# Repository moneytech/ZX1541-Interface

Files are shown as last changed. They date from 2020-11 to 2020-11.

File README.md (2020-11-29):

# ZX1541-Interface
An interface for the Sinclair ZX-81, with which you can use Commodore VC-1541 floppy drives.

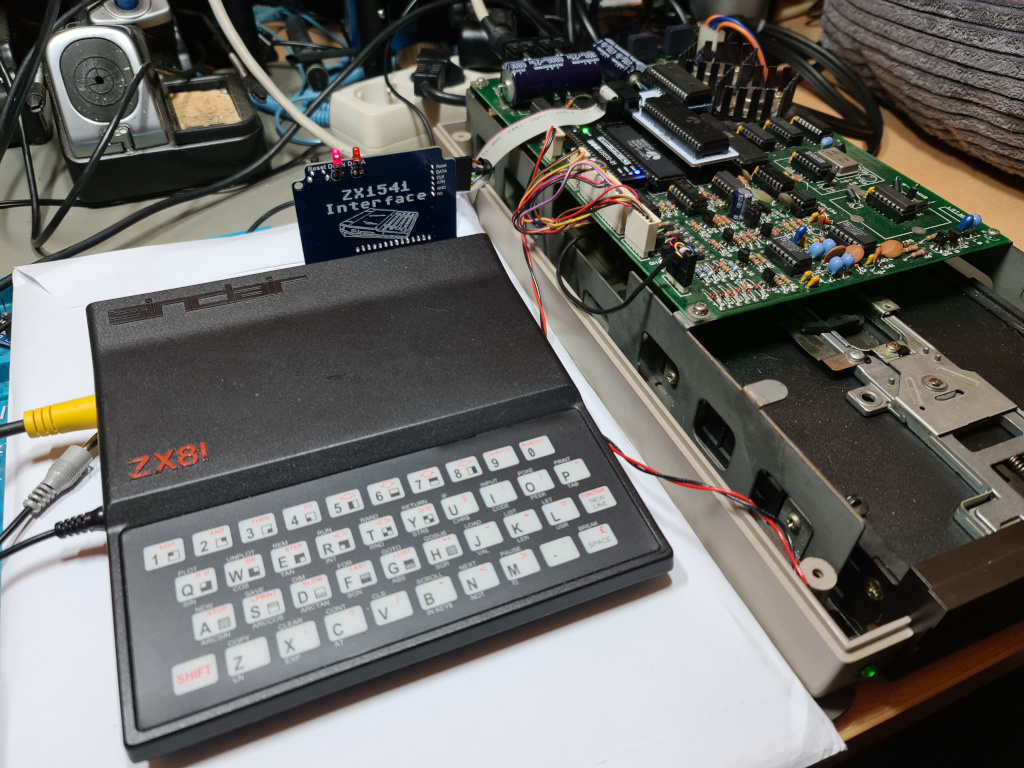
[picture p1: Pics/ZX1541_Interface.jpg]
Image of 1541 ZXInterface


Inspired by this post (https://forum.tlienhard.com/phpBB3/viewtopic.php?f=2&t=3218), I rebuilt the interface. 

The idea originally came from Luis C. Grosso
and was developed in 2004 for the model CZ1500 (a relabelled Timex Sinclair 1500)).

In 2006 Jarek Adamski took up the subject and made some modifications for use with a Sinclair ZX-81.

For this purpose, there is also a website with further information at http://8bit.yarek.pl/interface/zx81.zx1541/index-de.html.

Unfortunately most of the downloads are no longer available there. Whatever files I could find on the internet, I uploaded into this repository. 

I then created a new schematic using the information available there. Additionally some modifications from the above mentioned thread were included.

The board is designed to fit into an old case of the original Sinclair 16kb RAM expansion.

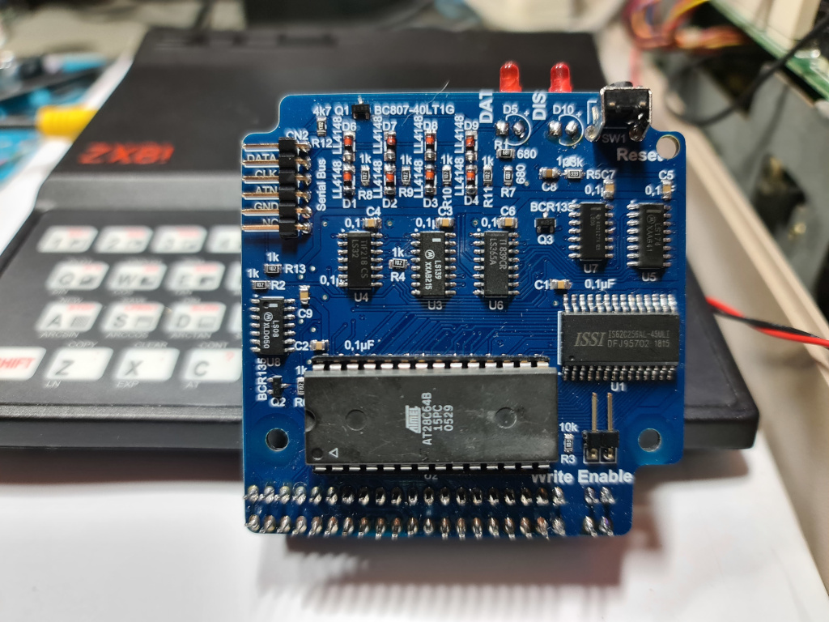
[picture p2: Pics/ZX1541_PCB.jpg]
Image of 1541 ZXInterface PCB


For the interface to work, a memory expansion is required. Without it there is not enough memory available for the extension to work. The best way to do this is to upgrade the ZX-81 internally.

The interface is equipped with an EEPROM, which contains the firmware. This can be called with the following command:

    RAND USR 8192

In firmware version 1.3 the start screen looks like this:

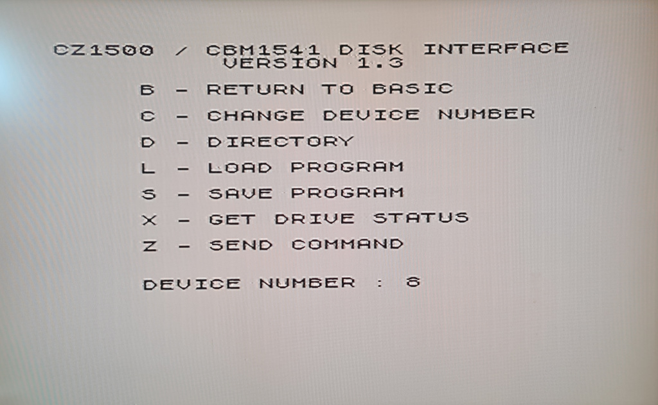
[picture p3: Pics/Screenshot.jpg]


## Parts List ##

Here is the list of all required parts

|Designator|Item|Type|
|---|----|----|
|U1|IS62C256AL-45ULI|SO28|
|U2|AT28C64B-15PC|DIP28|
|U3|74LS139|SO16|
|U4|74LS32|SO14|
|U5|74LS174|SO16|
|U6|74LS365|SO16|
|U7|74LS06|SO14|
|U8|74LS08|SO14|
|Q1|BC807-40|SOT23|
|Q2-3|BCR135|SOT23|
|D1-4, 6-9|LL4148|miniMELF|
|D5|LED red 3mm|THT|
|D10|LED green, 3mm|THT|
|R1,7|680R|0805|
|R2,4,6,8-11,13|1K|0805|
|R3|10K|0805|
|R5|33K|0805|
|R12|4K7|0805|
|C1-7,9|100nF|0805|
|C8|1µF|0805|
|CN2|Pin Header, RM2.54mm, 6pos, right angle|THT|
|JP1|Pin Header, RM2.54, 2pos.|THT|
|SW1|Push button, 6x6mm, right angle|THT|
|For U2|IC Socket 28pos.|DIL28|

Unless otherwise stated:
resistors tolerance 5% or better
Capacitors: X5R or better, 16V or higher

In addition, an approx. 60cm long, 6-core cable, a 6-pin DIN socket in "horseshoe shape" and a 6-pin female connector strip for the connection cable to the floppy is required.

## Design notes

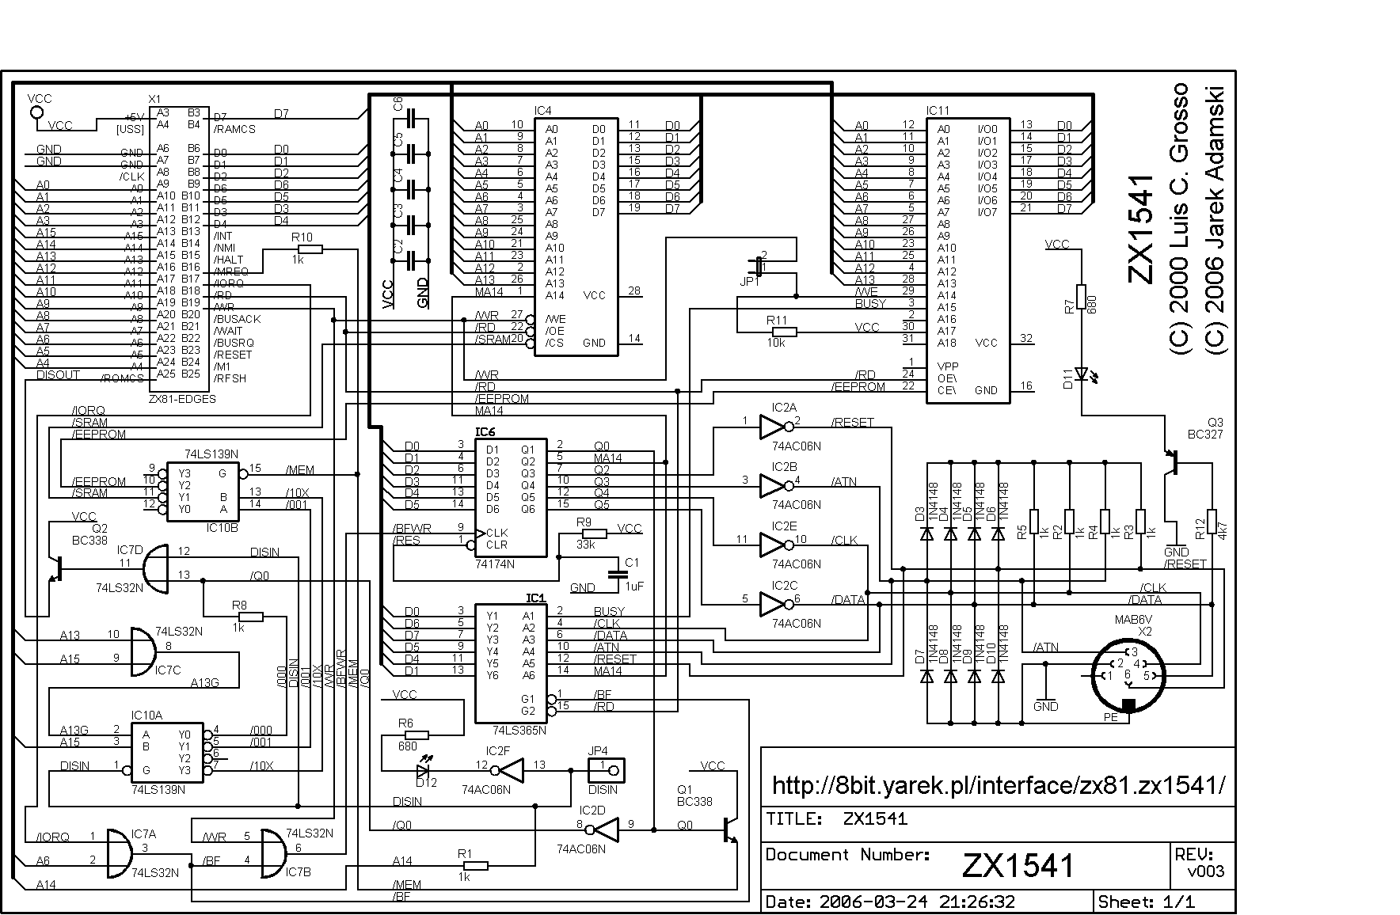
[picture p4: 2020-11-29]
files_found_on_the_internet/Schematics/zx1541v003.png

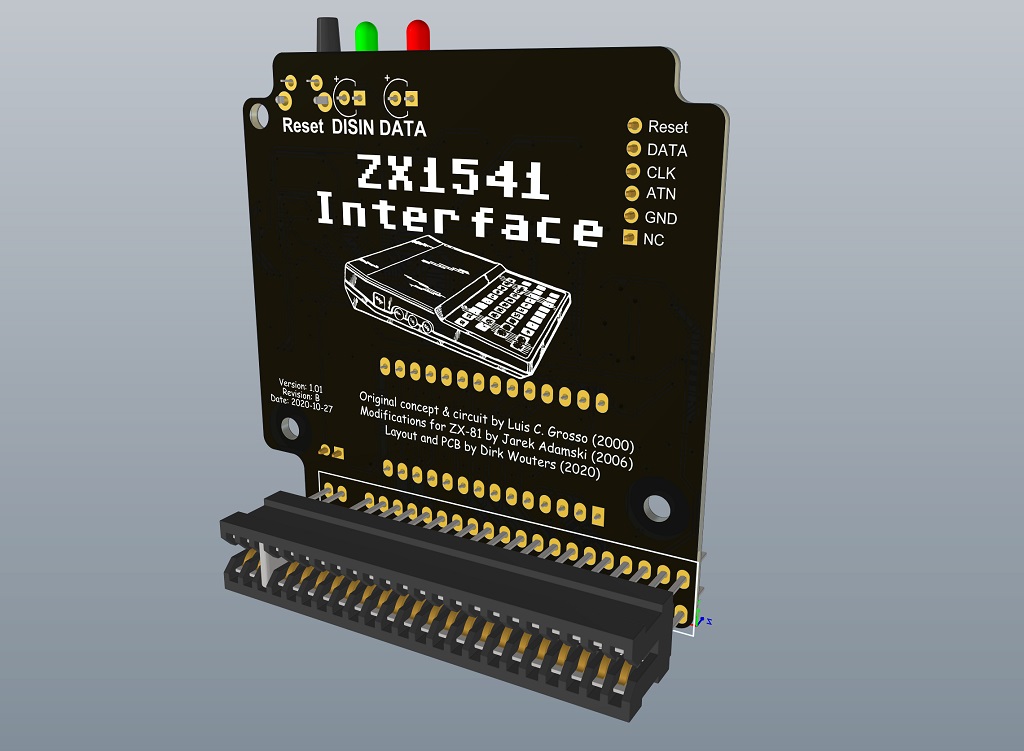
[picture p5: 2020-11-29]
Pics/PCB_back.jpg

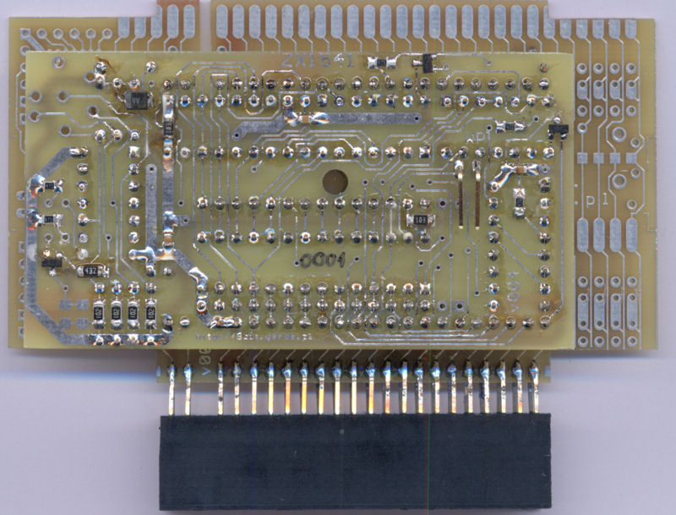
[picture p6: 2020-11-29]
files_found_on_the_internet/Pictures/0001c.jpg

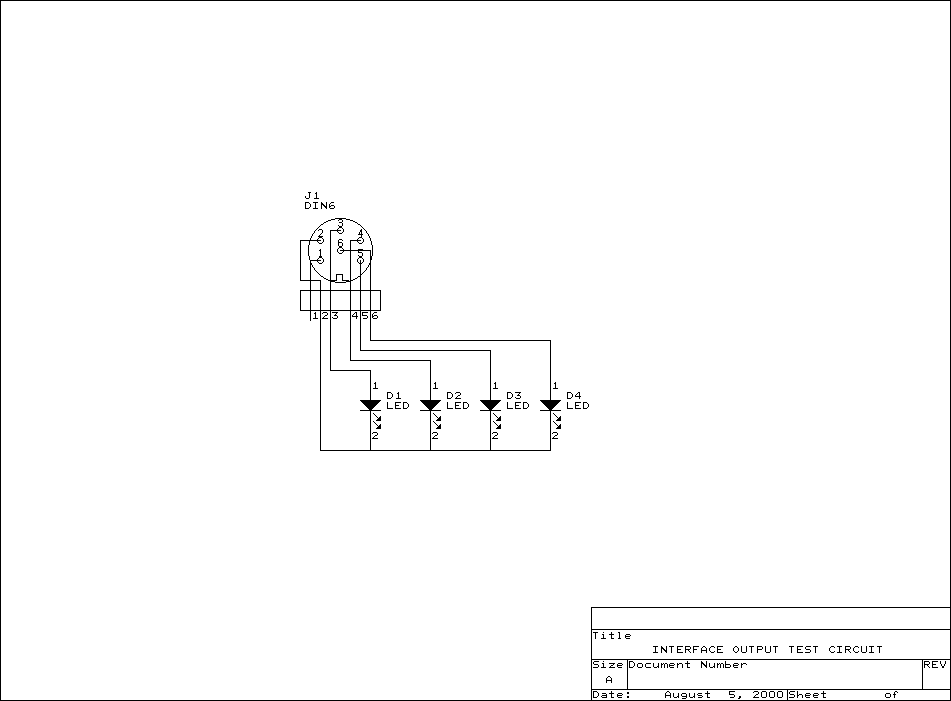
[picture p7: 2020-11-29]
files_found_on_the_internet/Pictures/LEDS.GIF

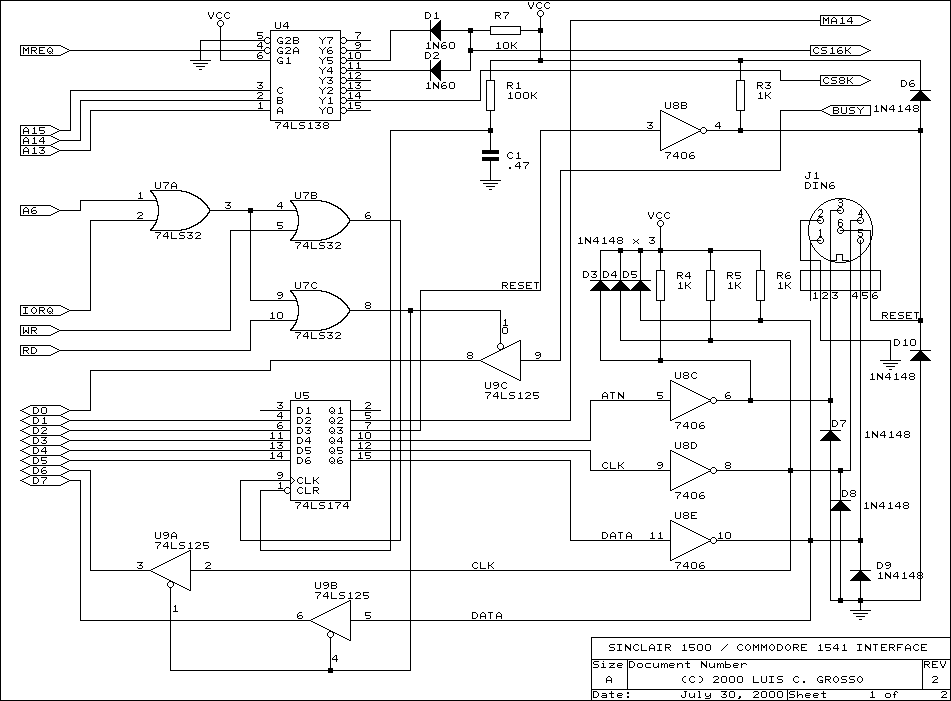
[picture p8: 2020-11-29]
files_found_on_the_internet/Pictures/1500DSK1.GIF

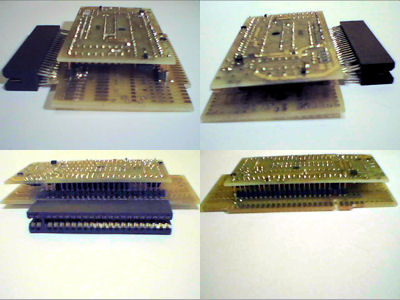
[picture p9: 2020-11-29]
files_found_on_the_internet/Pictures/0001b.jpg

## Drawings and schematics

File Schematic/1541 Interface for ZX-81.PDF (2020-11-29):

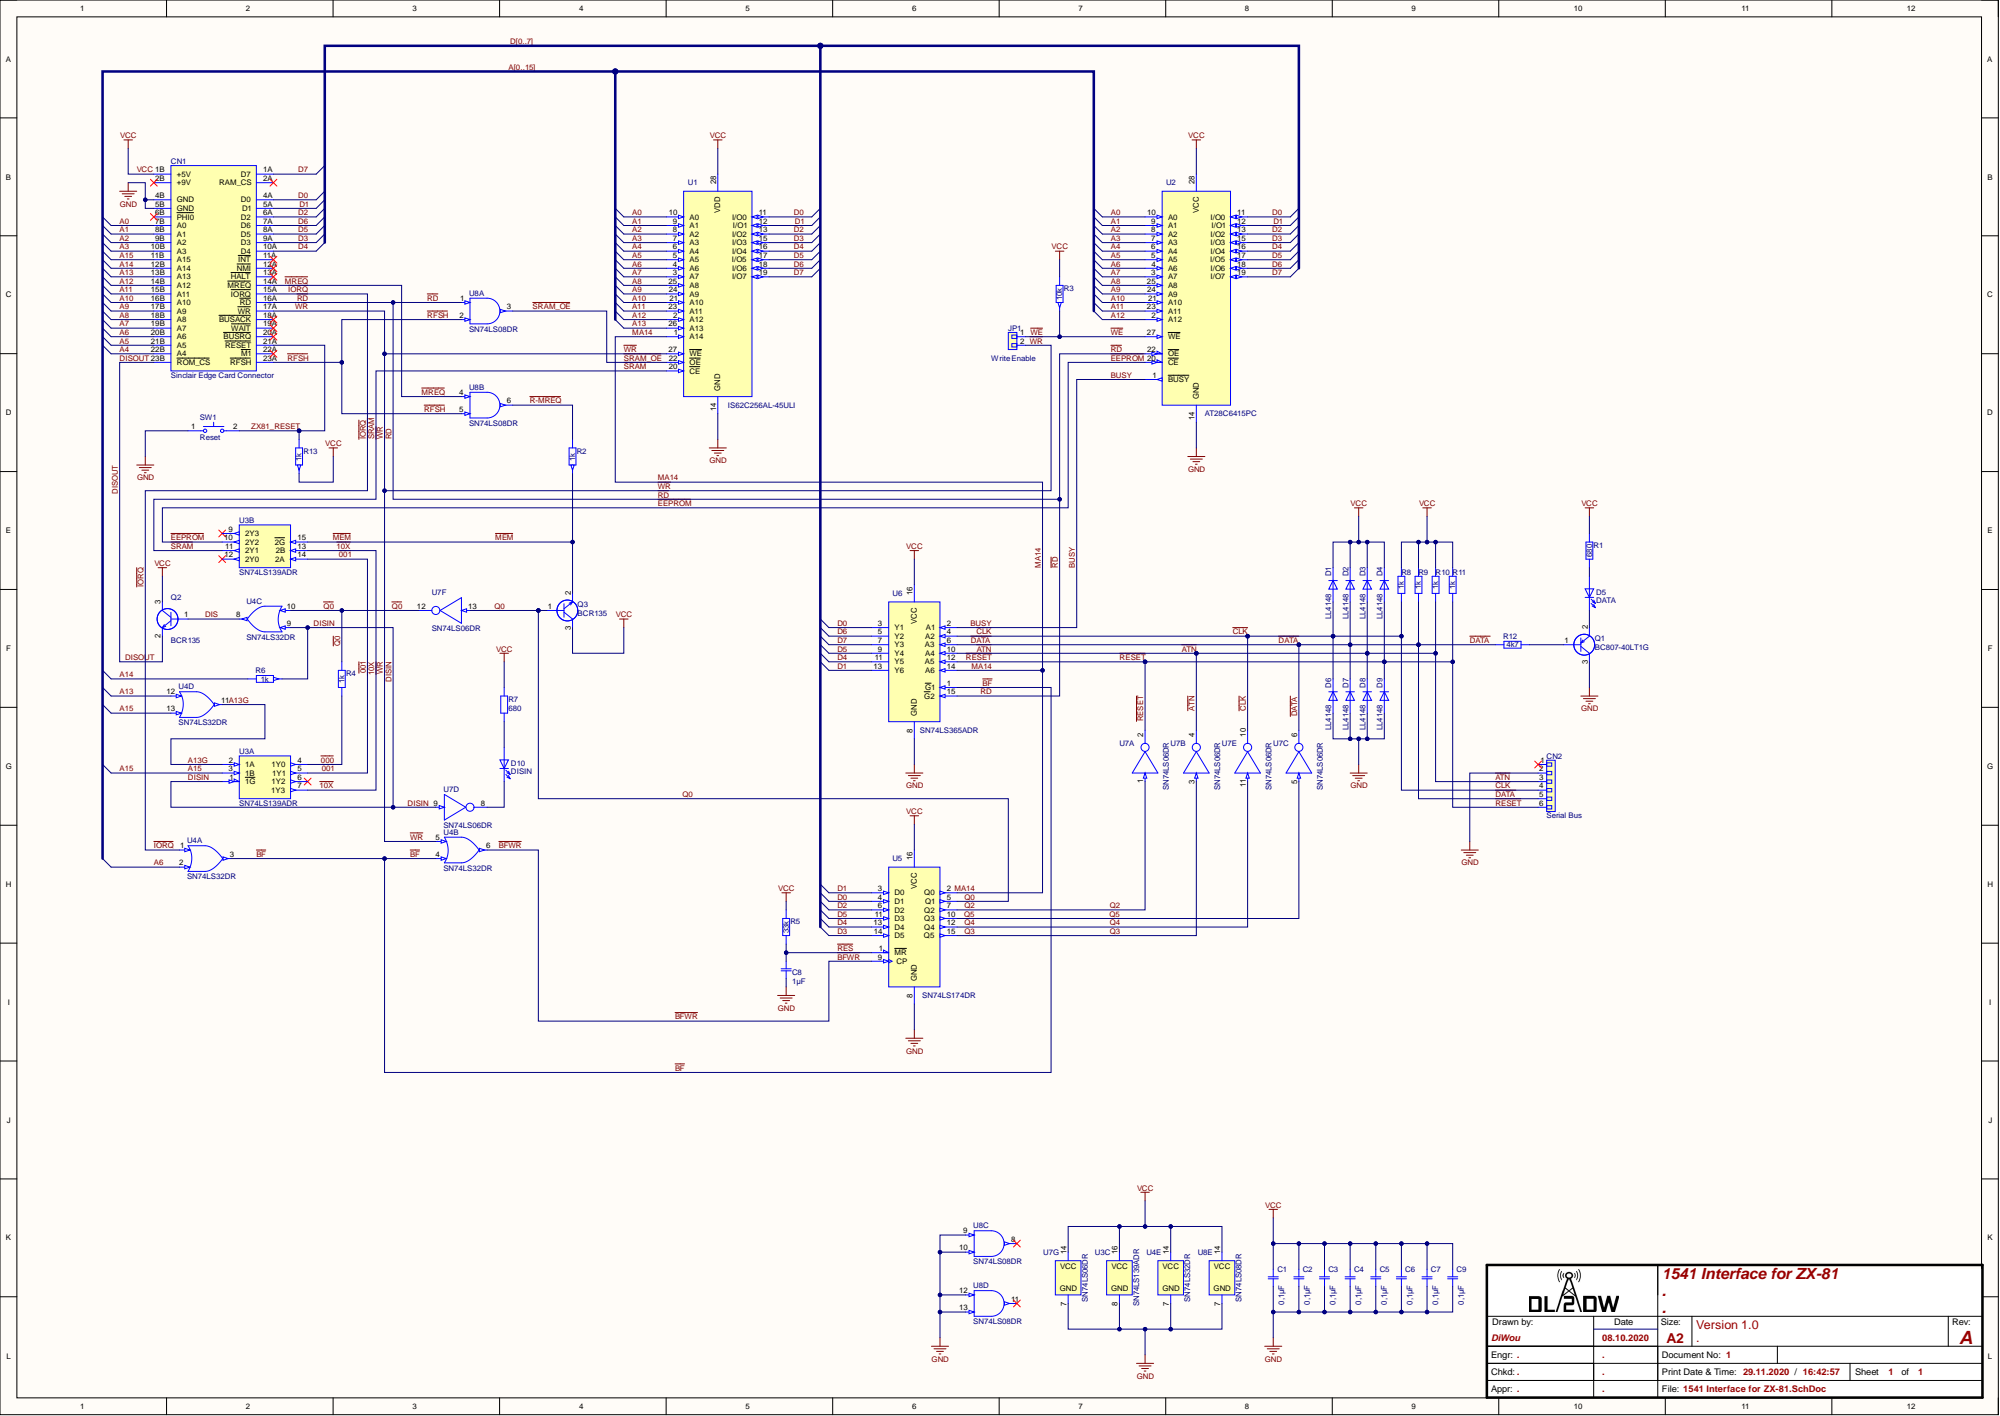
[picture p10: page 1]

VCC | VCC | VCC

Sinclair Edge Card Connector

RD
EEPROM

U3B | | MEM | | VCC

DISIN | U4B BFWR | Q0 | | RD

1541 Interface for ZX-81 . .

Engr: . | . | Document No: 1

Chkd: . | . | Print Date & Time: 29.11.2020 / 16:42:57 | Sheet 1 of 1

Appr: . | . | File: 1541 Interface for ZX-81.SchDoc

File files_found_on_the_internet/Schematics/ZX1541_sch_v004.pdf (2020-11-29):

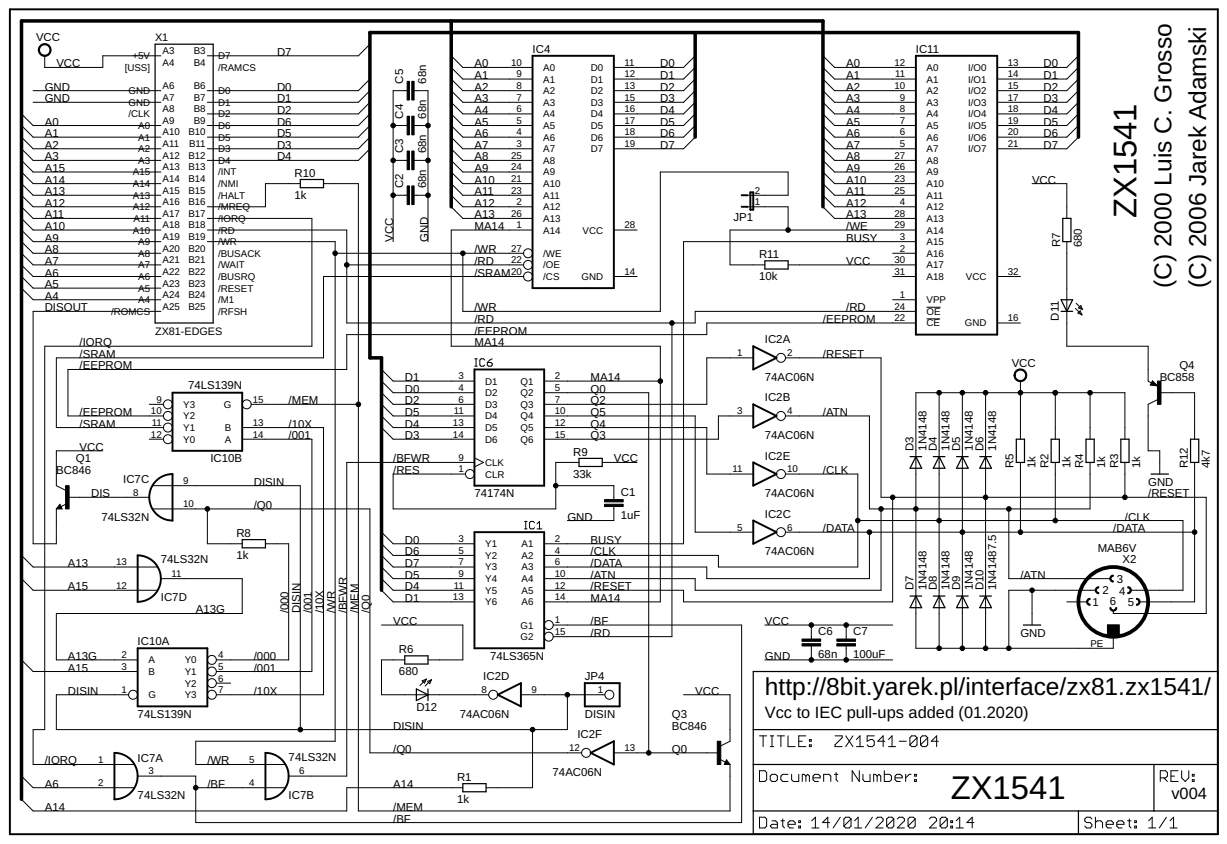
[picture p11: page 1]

http://8bit.yarek.pl/interface/zx81.zx1541/
Vcc to IEC pull-ups added (01.2020)
